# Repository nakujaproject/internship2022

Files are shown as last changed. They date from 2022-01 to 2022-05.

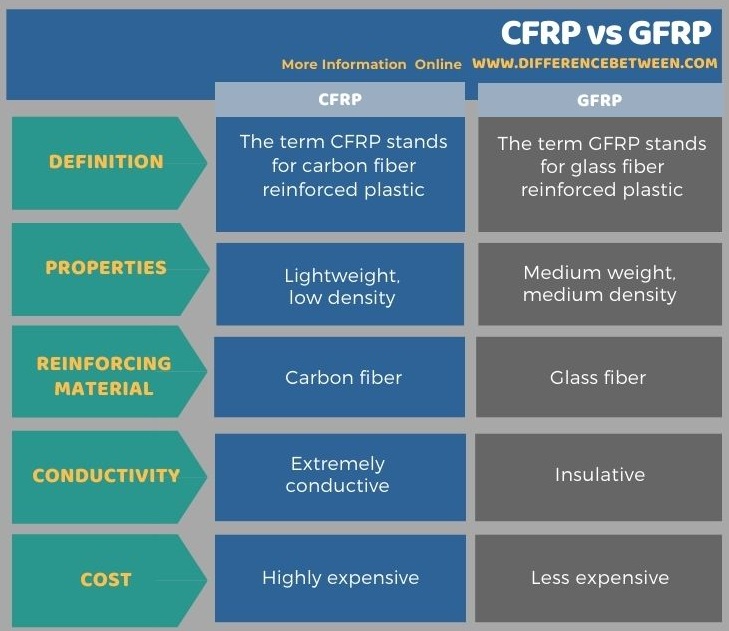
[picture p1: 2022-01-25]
Airframe/Week 1 progress/Difference-BetweenCFRP-and-GFRP-Tabular-Form.jpg

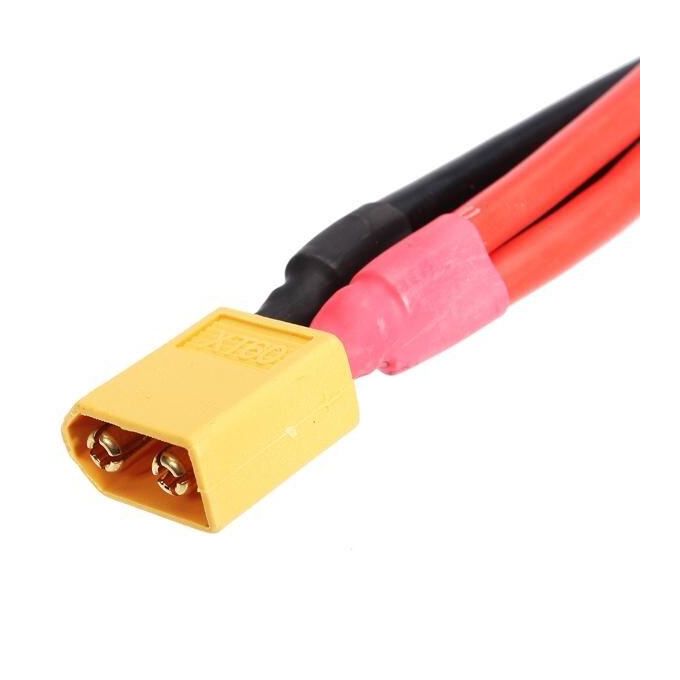
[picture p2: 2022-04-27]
avionics/AvionicsBay/xt60.jpg

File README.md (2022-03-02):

# Nakuja intern 2022

[PPT Slide](https://docs.google.com/presentation/d/1BPh0vmiUIqLUqmDDqvoZCn27pKPHvCULg1EC3PQ6zpk/edit?usp=sharing)
(https://docs.google.com/presentation/d/1BPh0vmiUIqLUqmDDqvoZCn27pKPHvCULg1EC3PQ6zpk/edit?usp=sharing)

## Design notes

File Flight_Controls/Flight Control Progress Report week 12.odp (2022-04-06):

## Internship 2022 Progress report format for Flight Control team Name: kariuki robert mukono

## Tasks completed last week

~ Preparations were made for the test flight.

~ Most of the time has been spent trying to familiarize ourselves further and further with the current code, following the directive to effectively ensure zero roll – for the sake of its modification and improvement.

## Example of code being studied

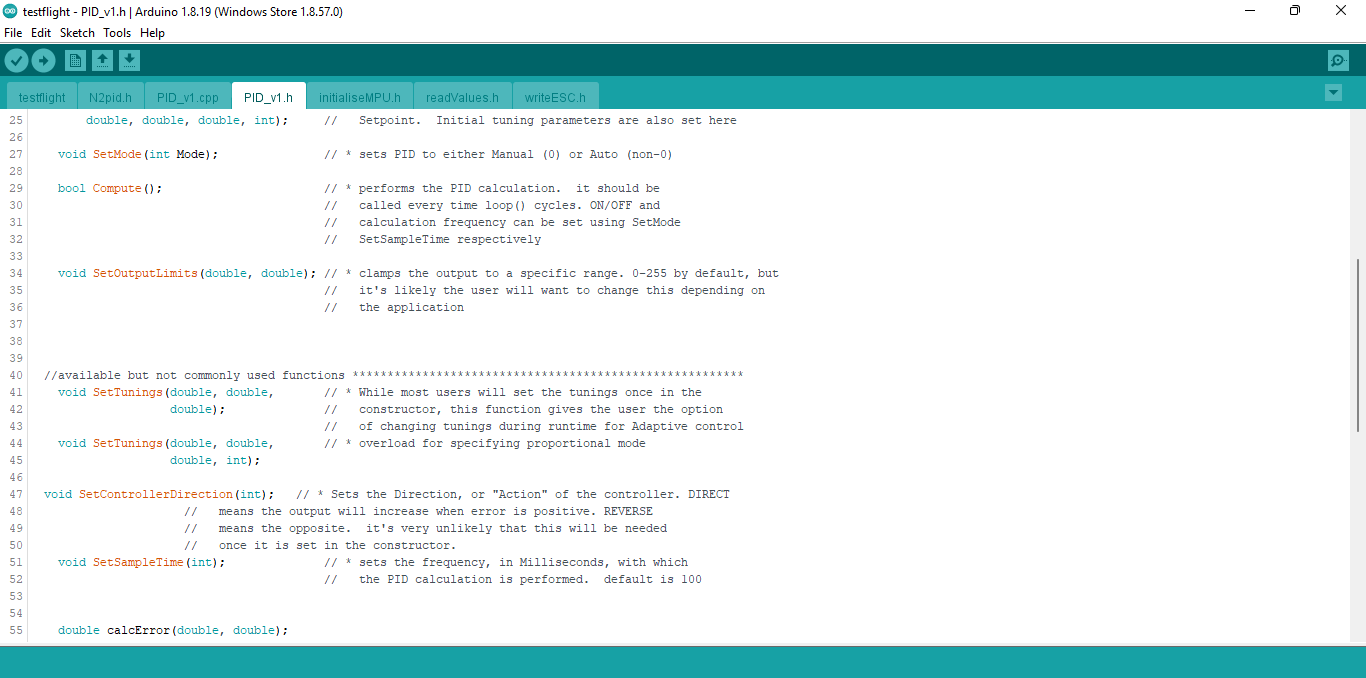
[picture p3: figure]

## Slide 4

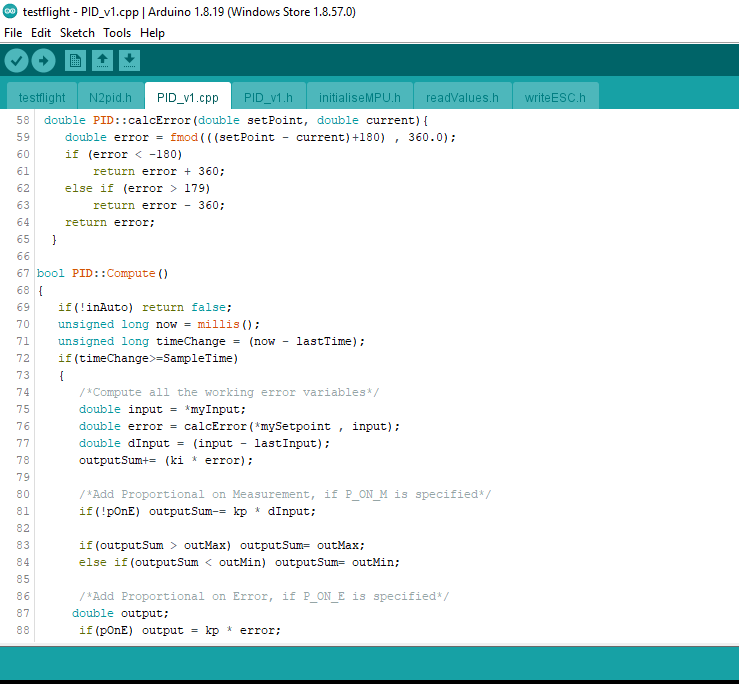
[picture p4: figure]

## Tasks in this week

~ This week we purpose to finish studying the code.

~ We also purpose to begin refining the current code.

~ We also purpose to do preliminary tests to test the effectiveness of the code.

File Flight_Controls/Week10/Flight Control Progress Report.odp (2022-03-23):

## Internship 2022 Progress report format for Flight Control team Name: kariuki robert mukono

## Tasks completed last week

- [#25] … Testing the functioning of the IR sensor

~Several tests were done at the incorporation of the IR sensor to the system, until it became functional.

~ It was noted that for proper functioning, the IR sensor must be hid from direct sunlight since it UV rays.

## [#26] … Displaying the motor speeds

~ The team strived to display the motor speed on the Arduino IDE.

~There were many challenges in the process, but finally the team was able to display the motor speed.

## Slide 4

[#27] … Motor Design

~ We designed a motor for the airframe team for the sake of simulation

## Tasks in this week

- [#25] …Further PID Tuning

~ This week we purpose to further do the PID tuning until we obtain optimum values.

~ We also purpose to incorporate RTOS into the code

~ We also purpose to do a test flight to test the effectiveness of the code.

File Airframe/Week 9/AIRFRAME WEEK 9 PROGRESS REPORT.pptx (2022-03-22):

## AIRFRAME WEEK 9 PROGRESS REPORT

BY MARK ODHIAMBO &
VIVIAN MWANGI

## GITHUB #138 NOSE CONE 3D PRINTING

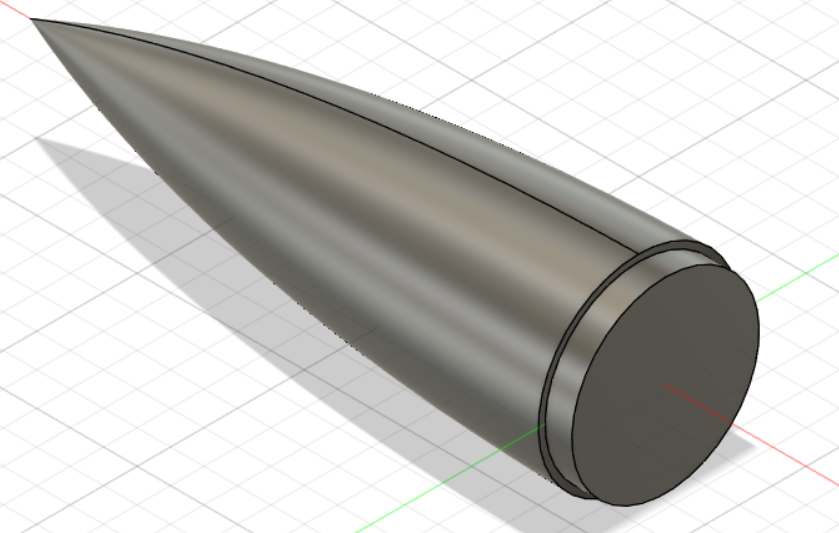
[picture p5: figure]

## GITHUB #137 RECOVERY SYSTEM

PURCHASE OF MATERIALS
WORK IN PROGRESS

## GITHUB #139 FOURTH FABRICATION.

This is the research and fabrication of the forth fabrication.
This includes the following:
- The mold cover.
- The fins.
- The accuracy.

## GITHUB ISSUE TO BE DONE.

- Github # Forth fabrication.
- Github # Ejection test

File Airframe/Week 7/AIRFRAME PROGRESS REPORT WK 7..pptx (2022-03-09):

## AIRFRAME PROGRESS REPORT WK.7 MARK ODHIAMBO AND VIVIAN MWANGI.

## GITHUB #114[UPDATED THE CAD DESIGN.]

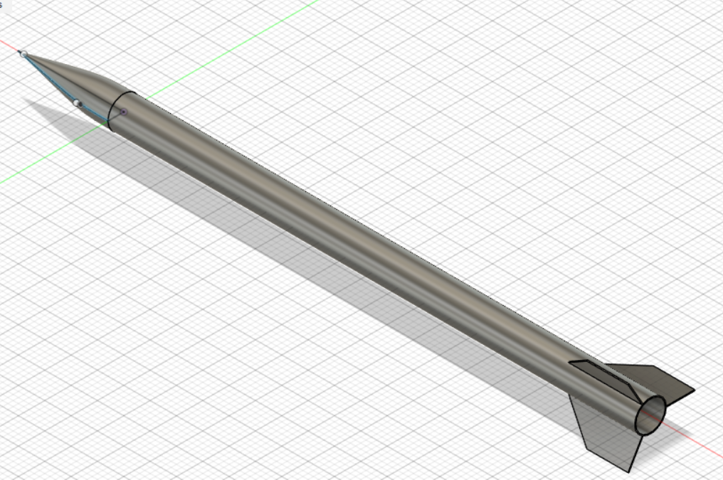
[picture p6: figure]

## GITHUB #93[CFD SIMULATION]

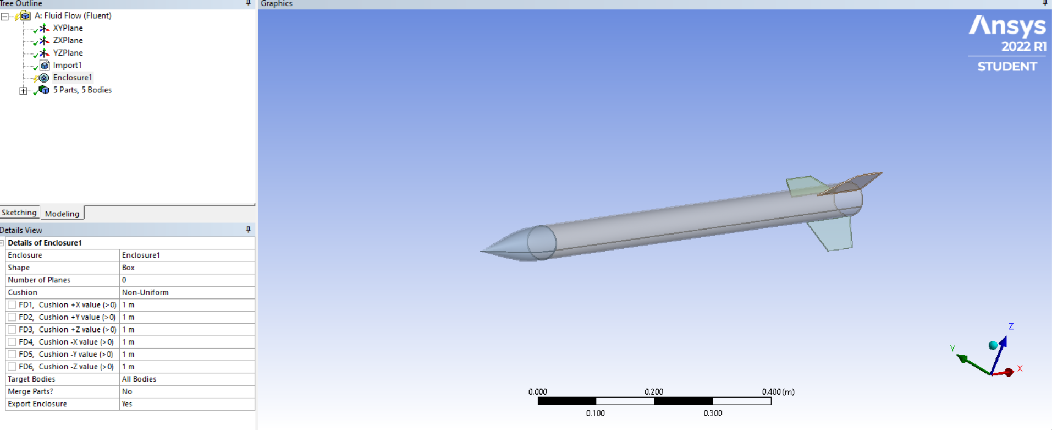
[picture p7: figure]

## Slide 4

Error in the cfd simulation.

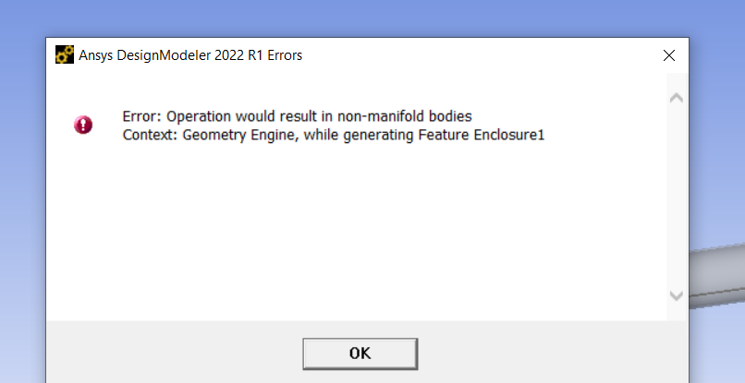
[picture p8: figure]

## GITHUB #106[THIRD FABRICATION]

The results of the third fabrication were better than that of the 2nd one the body tube had less air bubbles.
The tube should be turned to reduce thickness.

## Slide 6

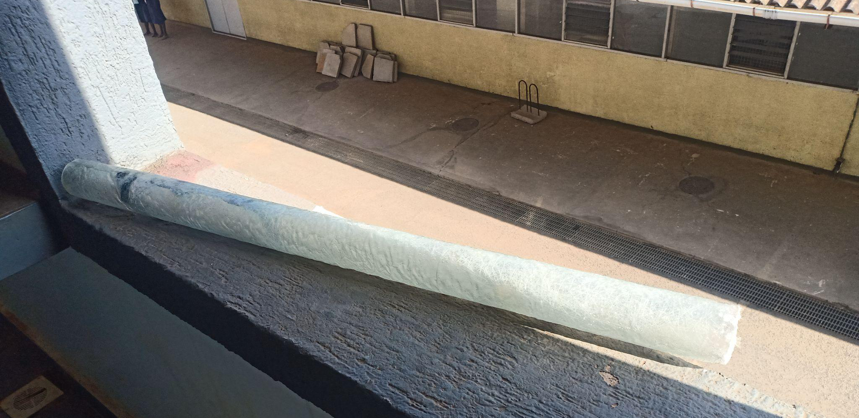
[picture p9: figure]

## TASKS TO BE DONE.

GITHUB #115 [3D PRINT NOSE CONE]
GITHUB #116 [MATERIAL ACQUISITION(RESIN)]
GITHUB #117 [POST FABRICATION OF BODY TUBE]

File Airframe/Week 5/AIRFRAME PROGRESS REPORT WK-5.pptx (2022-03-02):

## AIRFRAME PROGRESS REPORT

MARK ODHIAMBO & VIVIAN MWANGI

## [Github issue #95]Research on rocket stability tests

This is the test to be done to ensure that the rocket is stable and does not destablize during launch.
So the method found was the swing test.

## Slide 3

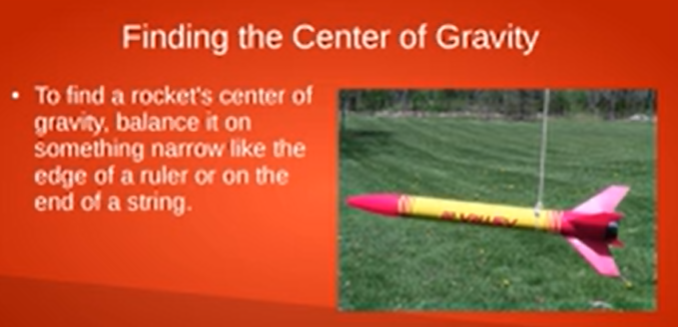
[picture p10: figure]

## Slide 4

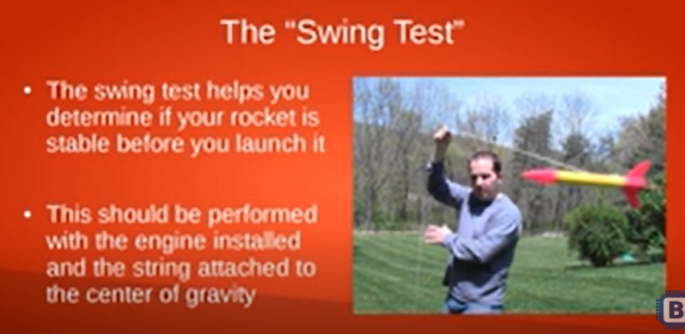
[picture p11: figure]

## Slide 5

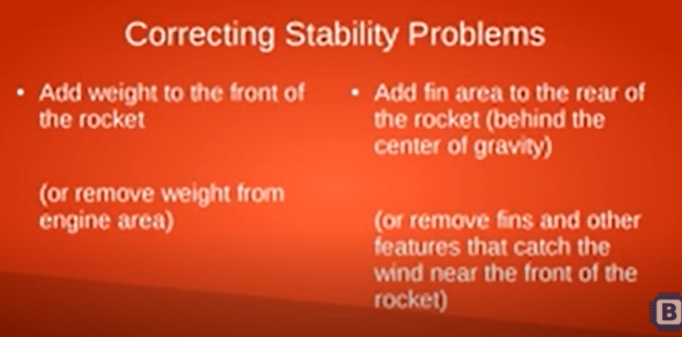
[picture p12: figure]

## [Github issue#78]Engine block design

This is the block to hold the engine in place

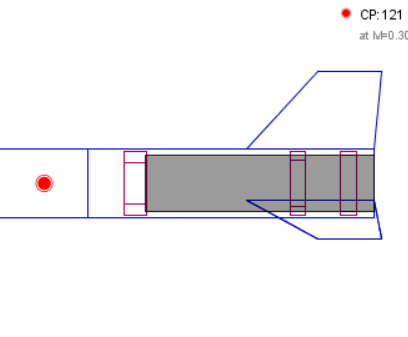
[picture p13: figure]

## CAD Design

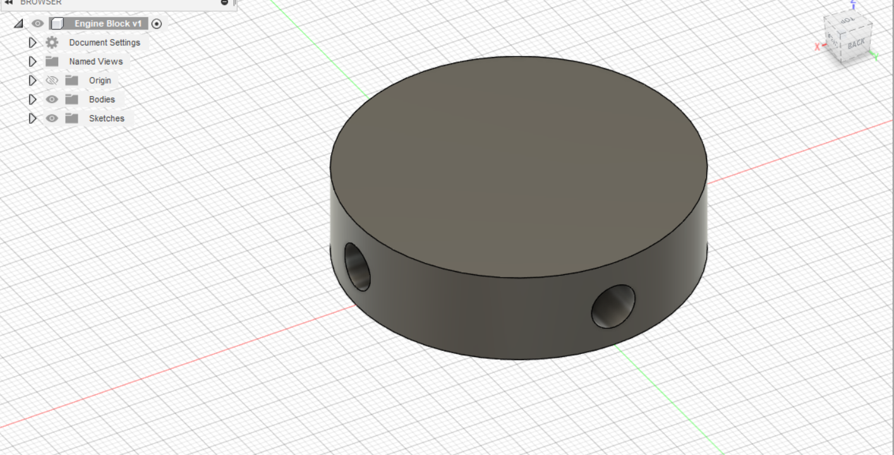
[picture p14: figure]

## [Github issue#80]Camera mount design

This is the bay which will shield host the camera of the rocket

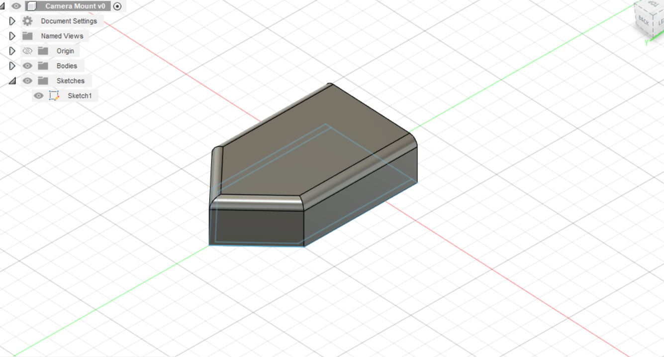
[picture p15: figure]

## [Github issue#80] Tee slot design

This is the launch rug or the component that will hold the rocket for its initial launch

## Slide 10

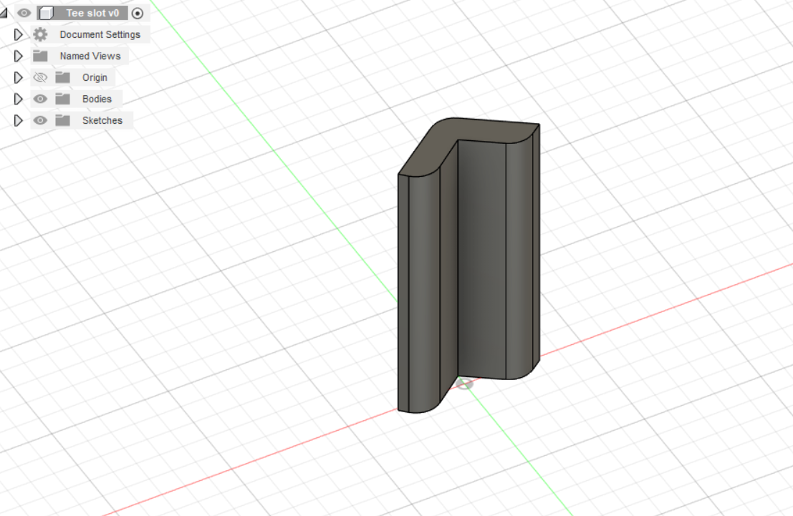
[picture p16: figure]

## Issues to be done.

- Research of fabrication of fins and nose cone[Github issue#94]
- Preparation for the third round of fabrication

## TIMELINE.

- WEEK 1-material SELECTION, ANALYSIS AND COST
- WEEK 2-DESIGN AND SIMULATION.
- WEEK 3-SIMULATION CORRECTIONS.
- WEEK 4-ASSEMBLY AND FABRICATION.
- WEEK 5-ASSEMBLY AND FABRICATION.
- WEEK 6- RECOVERY SYSTEM
- WEEK 7-FINALISATION.
- WEEK 8-TAKE OFF.
- PRONE TO CHANGE AS PER THE SITUATION.

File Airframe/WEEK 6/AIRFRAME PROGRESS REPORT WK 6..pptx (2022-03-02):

## AIRFRAME PROGRESS REPORT

Mark Odhiambo & Vivian Mwangi

## Github #104[Update of the Rocket in openRocket.]

This is the updated rocket design factoring both the design consideration of both the avionics and flight control.

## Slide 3

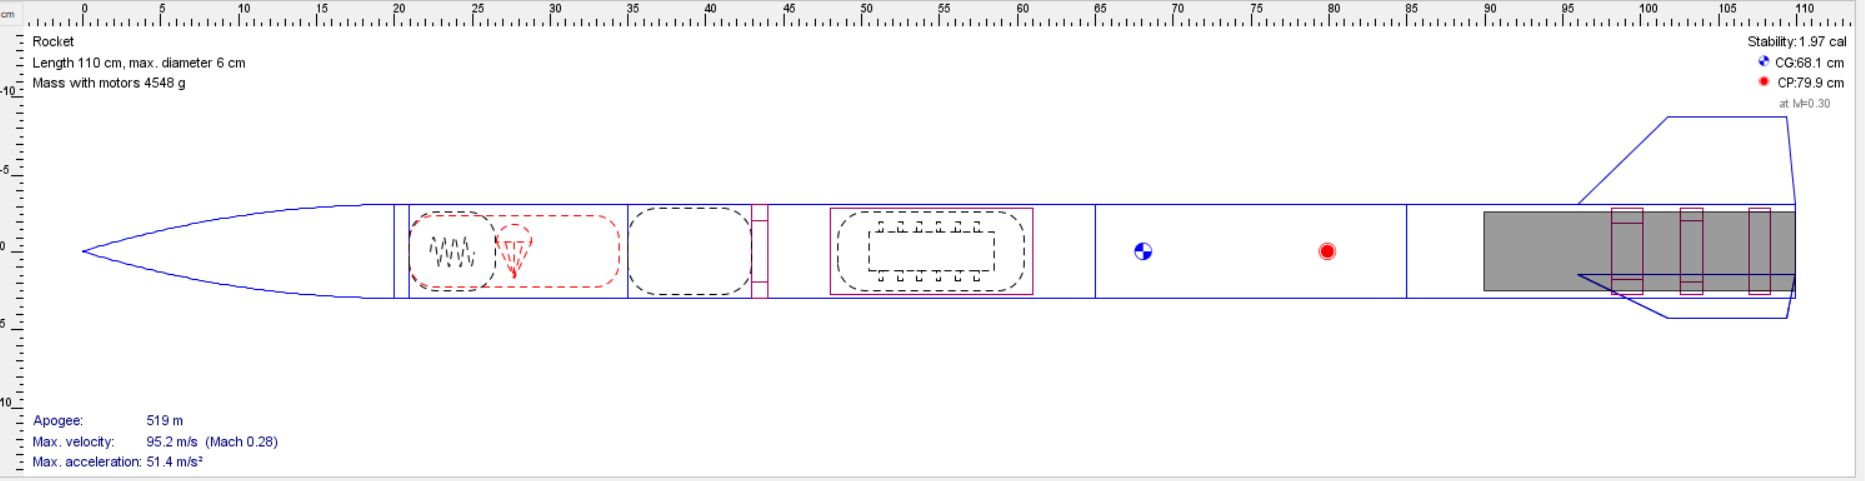
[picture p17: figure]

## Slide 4

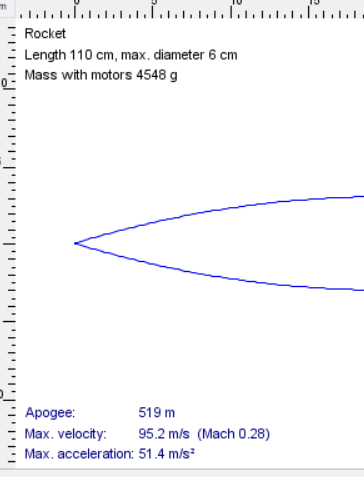
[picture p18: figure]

## Github #94 Research and fabrication of fins

It was determined that for accuracy the cones will be printed.
This was one of the factors that where considered for the rocket redesign.

## Github #105 Rocket recovery system

Different types of deployment.
- Single
- Dual

## Testing of recovery system.

Ground deployment.
After the final configuration of the rocket the final.
The rocket is tested by ground deployment. This is when the rocket is kept to the ground and ejected.

## Issues to be done

[Github #106] Third fabrication.
[Github #105] Rocket recovery system

## TIMELINE.

- WEEK 1-MATERIAL SELECTION, ANALYSIS AND COST
- WEEK 2-DESIGN AND SIMULATION.
- WEEK 3-SIMULATION CORRECTIONS.
- WEEK 4-ASSEMBLY AND FABRICATION.
- WEEK 5-ASSEMBLY AND FABRICATION.
- WEEK 6- RECOVERY SYSTEM
- WEEK 7-FABRICATION.
- WEEK 8-TAKE OFF.
- PRONE TO CHANGE AS PER THE SITUATION.

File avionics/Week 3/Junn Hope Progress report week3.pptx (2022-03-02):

## Nakuja Internship Avionics Progress Report Week 3 Junn Hope

## Tasks completed last week

- [#Issue 30] : Research on camera module
- [#Issue 51]: Inquire about GEGIS drone
- [#Issue 30] : Research on Ground Station Dashboard – In progress

## [#Issue 30] : Research on camera module

- We researched on plausible camera modules that we can use for video transmission in real time form the rocket to the ground station.
- We tested two modules:
  1. ESP32CAM
  2. FPV Drone Camera
ESP32 CAM FPV Drone camera

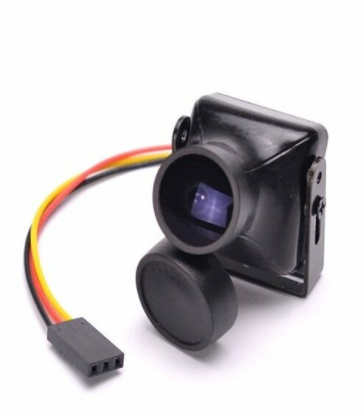
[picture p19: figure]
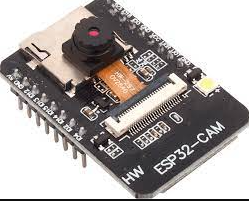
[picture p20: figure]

## ESP32 CAM

- The ESP32 cam provided clear video feed over a short range, beyond which the clarity was significantly reduced and video lag increased.
- However, these results are dependent on the Wi-Fi strength of the network to which the ESP32 is connected to.
- The results of the test carried out are as shown in the figures below:
Wi-Fi signal strength

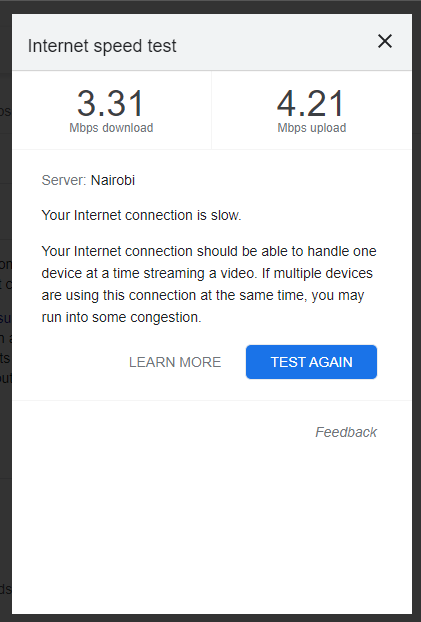
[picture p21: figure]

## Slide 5

- Clarity of ESP32 at varying distances

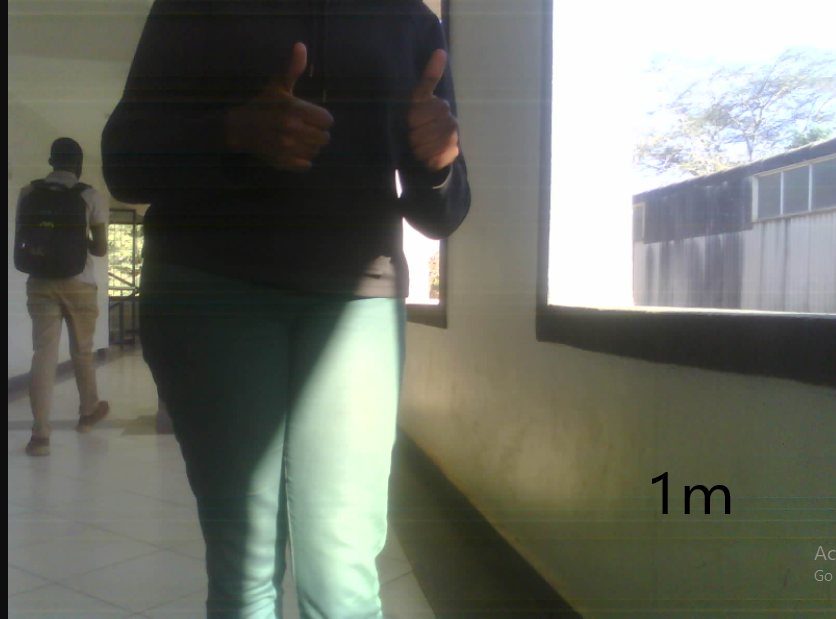
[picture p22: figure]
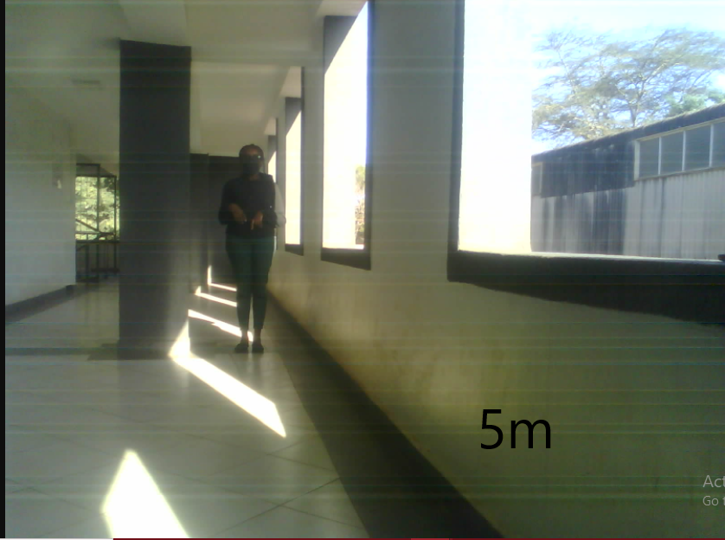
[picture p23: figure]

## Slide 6

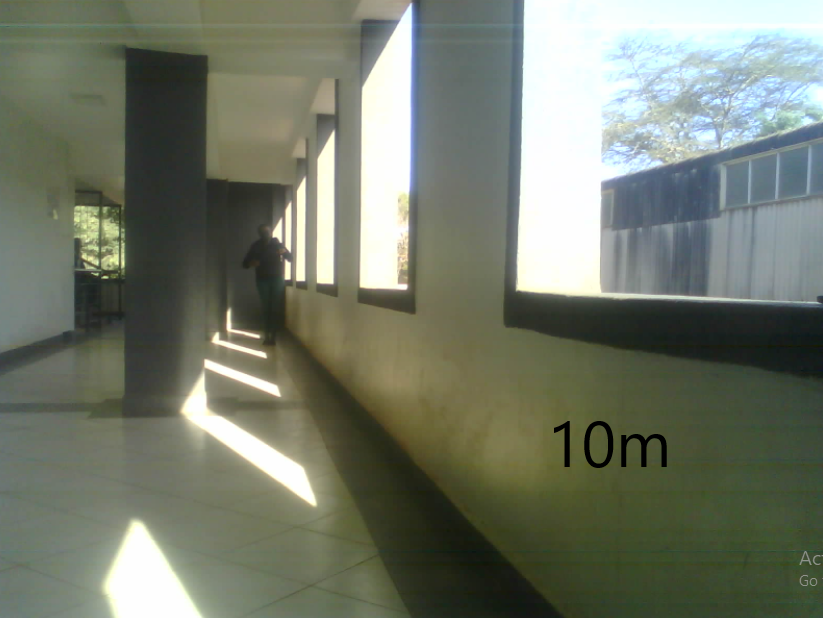
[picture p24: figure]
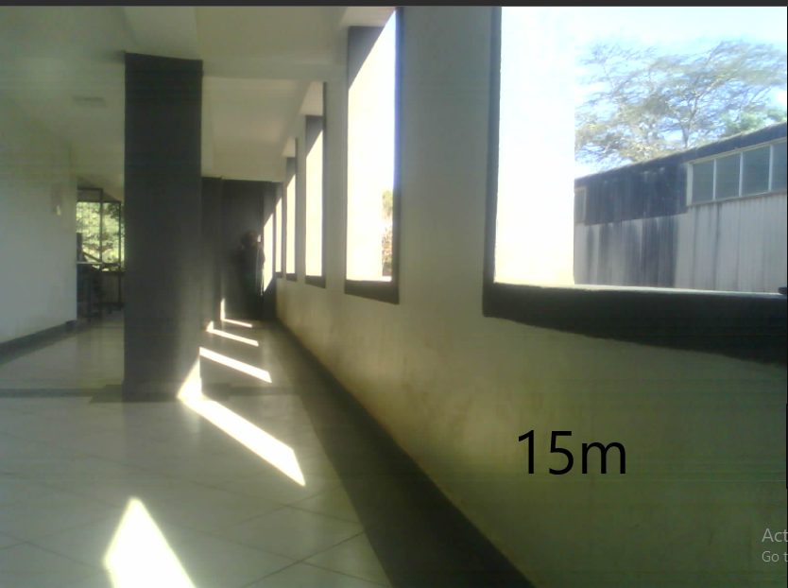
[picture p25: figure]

## FPV Drone Camera

- We tested the FPV drone camera that gave impeccable results over a greater distance of up to 1km.
- We noticed that the pointing direction of the receiving and transmitting antennas affected the clarity of the reception.
- The camera and its antennas must be connected to 12v supply, which is 4.6volts above our intended 7.4V supply.
- The test results are as shown in the figures below

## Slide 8

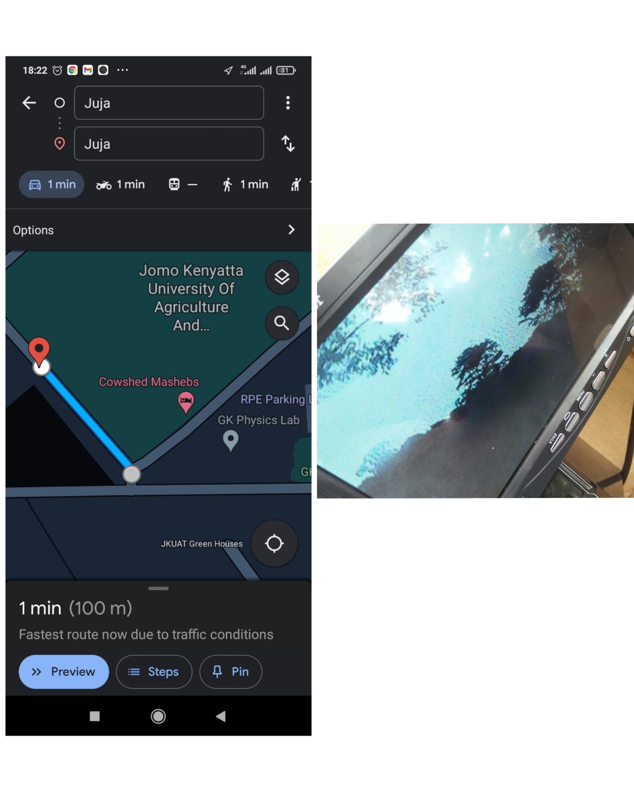
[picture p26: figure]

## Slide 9


## [#Issue 51]: Inquire about GEGIS drone

- Following week 2’s inquiry on the drone, we got the go ahead to use the drones for the tests.
- The tests are to be done on Week 5.

## Tasks in this week

- [#Issue 3]: Avionics bay design
- [#Issue 18] : Launch pad design
- [#Issue 30] : Research on Ground Station Dashboard
- [#Issue 31] : Research on apogee detection logic
- [#Issue 26] : Improve on Kalman filter performance

## Timeline

Month | Intern week | Tasks
Jan | Week 1 | Onboarding Getting acquainted with avionics and telemetry resources
| Week 2 | Research on ground station & ground station dashboard Research on camera module Research on Data transmission
| Week 3 | Avionics bay design Launch pad design
Feb | Week 4 | Research on apogee detection logic Improve Kalman filter performance
| Week 5 | Program Avionics and Telemetry boards
| Week 6 | Test the boards
| Week 7 | Testing and launch of N2

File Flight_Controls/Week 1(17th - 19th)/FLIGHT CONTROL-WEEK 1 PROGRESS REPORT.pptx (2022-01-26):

## Nakuja Internship Week 1 Progress Report

FAITH CHELANGAT
&DERRICK KIRIMI

## Tasks completed last week

- Familiarise myself with the project
- Soldering on the prototype
- Redesigning the reaction wheel

## Tasks to be completed in the following week

- Design of the N2 reaction wheel
- Logging of data onto the SD card
- Research on the mounting case and safety cage of the reaction wheel

## schematic


## Timeline

Month | Week | Tasks
January | Week1 | Familiarising with the N1/N2 project Soldering of prototype flight control PCB Research on the design of reaction wheel
| Week2 | Design of the N2 reaction wheel Logging of data onto the SD card Research on the mounting case and safety cage of the reaction wheel
| Week3
| Week4

February | Week1 | Design of the mounting case and safety cage of the reaction wheel
| Week2 | Research on Kalman Filter and ways to improve it
| Week3
| Week4

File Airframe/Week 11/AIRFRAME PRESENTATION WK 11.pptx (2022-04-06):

## Airframe weekly progress report.

MARK ODHIAMBO & VIVIAN MWANGI.

## Github #155: test flight review.

This is the review of the mistakes of the test flight.
- Recovery system.
- Fins
- Body tube

## REcovery system

Test under actual conditions
Attachment of the parachute
Release of the parachute

## fins

Orientation of the fins.
Attachment of the fins to the rocket

## Body tube

Inner body tube for component placing.
The launch rage redesign.
Extra: Painting the body tube

## Github #156: fifth fabrication.

This is the research on method for improving the fifth fabrication.
- Mold release
- Torch gun or blowdryer.

## Tasks to be done.

#156: body tube fabrication.

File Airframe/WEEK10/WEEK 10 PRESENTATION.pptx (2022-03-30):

## WEEK 10 PRESENTATION AIRFRAME

BY VIVIAN MWANGI &
MARK ODHIAMBO

## TASKS COMPLETED THIS WEEK

- RECOVERY SYSTEM FABRICATION #137
- MATERIAL ACQUISITION(RESIN) &CONSUMABLES #116
- 3D PRINT NOSE CONE #115
- FOURTH BODY TUBE FABRICATION #152

## 3D PRINT NOSE CONE #115


## RECOVERY SYSTEM FABRICATION #137

- Parachute model was tailored to the required dimensions


## FOURTH BODY TUBE FABRICATION #152

- Improvements made:
  - Less air bubbles
  - Measurements taken into account


## TASKS IN THIS WEEK

- FIN SET FABRICATION #139
- NOSE CONE FABRICATION #138
- RECOVERY SYSTEM TESTING #153
- TEST LAUNCH #111

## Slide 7

THANK YOU!


-THE END-

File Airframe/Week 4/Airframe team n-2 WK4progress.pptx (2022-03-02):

## Airframe team n-2 rocket wk4

VIVIAN MWANGI
&
MARK ODHIAMBO


## CRADLE FABRICATION

- We started on cradle fabrication.
- This included marking out of the purchased wood blocks , cutting to required shapes and then filing to obtain a fine surface finish
- We assembled the fabricated wood to a stand plate for the purpose of enhancing stability.
- See illustration on the pictorial slide

## Cad design / Pictorial for cradle


## Body-tube fabrication

- We managed to make two prototypes for the body-tube.
- Method used:
    - We set out our workstation in an open area
    - We analyzed and read the chemical safety guidelines
    - We wrapped nylon paper on our body tube mold and stuck it with tape
    - We mixed resin and catalyst in directed proportions and stirred
    - Using a brush we applied the resin to the fiberglass until we obtained desired thickness
    - We left the fiber glass body tube to dry
    - We disassembled the nylon from the body tube

## Pictorial of fabricated body-tubes


## Analysis of the fabrication process

- From our first prototype, it was discovered that several air bubbles were formed after the body-tube dried.
- It was also discovered that the thickness of the body tube was very large and it was necessary to reduce the weight
- From our second prototype, we tried to eliminate the air bubbles and at the same time reduce the thickness of the tube
- The air bubbles were observed to have reduced significantly
- The thickness of the tube was smaller than anticipated
- The nylon laid at the beginning made the interior of the tube have wrinkles

## Defects present analysis

1. Formation of air bubbles
HOW TO REDUCE:
    - MAKE THE ANGLE OF APPLICATION/SPREADER AS LOW AS POSSIBLE TO AVOID SCRAPPING OFF FRESH RESIN
    - FIRMLY DRAG THE SPREADER USING LONG AND OVERLAPPING STROKES
    - CONSIDER USING A ROLLER FOR APPLICATION INSTEAD OF BRUSH
2. Formation of wrinkles on the interior
HOW TO REDUCE:
    - MAKE SURE THERES A TIGHT FIT BETWEEN THE BODYTUBE MOLD AND THE BASE NYLON PAPER USED TO AVOID WRINKLES FORMATION

## Tasks done this week

- BODY RIG DESIGN {GitHub issue # 79}
- BODY TUBE FABRICATION {GitHub issue # 82}
- ANALYSIS OF FABRICATION {GitHub issue # 89}
- SECOND FABRICATION OF BODY TUBE {GitHub issue #90 }
- ANALYSIS OF SECOND FABRICATION OF BODY TUBE {GitHub issue #91}

## Tasks in this week

- Computational simulation of the rocket [Github issue#93]
- Tee slot design [Github issue#80]
- Engine block design[Github issue#78]
- Camera mount design[Github issue#80]

## timeline

- WEEK 1-material SELECTION, ANALYSIS AND COST
- WEEK 2-DESIGN AND SIMULATION.
- WEEK 3-SIMULATION CORRECTIONS.
- WEEK 4-ASSEMBLY AND FABRICATION.
- WEEK 5-ASSEMBLY AND FABRICATION.
- WEEK 6- RECOVERY SYSTEM
- WEEK 7-FINALISATION.
- WEEK 8-TAKE OFF.
- PRONE TO CHANGE AS PER THE SITUATION.

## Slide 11

THE END
THANK YOU!

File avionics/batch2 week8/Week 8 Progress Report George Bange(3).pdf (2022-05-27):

# Week 8 Progress Report

ENE221-0109/2017
GEORGE BANGE

# Tasks

- Issue #157 (https://github.com/nakujaproject/internship2022/issues/157) : RTOS optimization
- Issue #158 (https://github.com/nakujaproject/internship2022/issues/158) : Ground Station Parachute Manual override
- Issue #159 (https://github.com/nakujaproject/internship2022/issues/159) : Write telemetry data to flash memory during flight

# RTOS optimization

2 queues instead of 1

Reduced number of data points being sent over LoRa

LoRa - we are sending timestamp,altitude and state

SD card/SPI flash memory - timestamp, altitude, raw and filtered gyro and acceleration values, state, gps latitude and longitude

# RTOS Queues


# Ground station Manual Override

Rocket watches out for data packets from ground station

Update state to deploy parachute if it fails

Update ground state to start sending gps data

# Write Data to SPI flash memory

ESP32 has 4MB non-volatile flash memory

Write to flash memory incase SD card fails like in test flight

# Tasks Next week

- Issue #160 (https://github.com/nakujaproject/internship2022/issues/160) : Test GPS inside fibre glass body tube
- Test software on breadboard

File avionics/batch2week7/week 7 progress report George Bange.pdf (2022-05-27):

# Week 7 Progress Report

George Bange
ENE221-0109/2017

# Tasks

- Measure Time taken to execute different tasks
- Implement Real Time OS
- Manual override for parachute ejection
- Launch Test

# Measuring Time per Task

We timed the tasks and noticed that GPS takes the most amount of time (2 s) hence

To leverage the dual-core nature of ESP32-S, we decided to divide the tasks between the cores using FreeRTOS library in ESP-IDF

Core 0: Fetch Telemetry Data and Write to SD Card

Core 1: Transmit data using LoRa

TASK | Frequency (Hz) | Time (ms)
BMP and MPU | 13.88 | 72
Kalman Filter | 53070 | 0.018
Check state | 445570 | 0.00122
Format Data | 550790 | 0.00118
LoRa | 4 | 250
GPS | 0.5 | 2000
SD Card | 31.8 | 31

# ESP-IDF FreeRTOS Queue implementation


# Manual Override for Parachute ejection

We implemented manual override for parachute ejection from ground station

A command is sent over LoRa from ground station to the rocket to deploy the parachute

Other commands also exist to change states from ground station

# Test Launch

We carried out the first N2 test launch on 22nd April at the Rugby field

LoRa Transmit task worked but the connection was lost at some point. This was probably due to damage of flight computer

The highest recorded altitude was 1870m.


Rocket at take-off

# Challenges and Lessons

- FreeRTOS: Corruption of heap, ESP kept resetting
- Manual override failed
- Parachute ejection code failed
- Damage of payload
- Queue kept filling up causing some readings to be dropped
- Some packets were corrupted

# Photos of Recovered Rocket


# Photos of Recovered Rocket


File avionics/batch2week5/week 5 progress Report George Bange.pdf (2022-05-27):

# Week 5 Progress Report

### George Bange ENE221-0109/2017

# Tasks Completed

- Issue #140 (https://github.com/nakujaproject/internship2022/issues/140) : Review LoRa Module connections

### - SD card module connection - Fabrication of new PCB - Visited PAUSTI

# ESP32 pinout

Studied the ESP32-S GPIOs and their common applications

Some pins can’t be used as digital output pins, these pins are 6,7,8,9,10,11,34,35,36 and 39

All GPIOs can be used as hardware interrupt pins

ESP32-S has:

i. 18 ADC interfaces
ii. | 4 SPI interfaces
iii. | 3 UART interfaces (only UART 0 and UART 1 are available for use)
iv. | 2 I2C interfaces
v. 2 DAC interfaces
vi. | 16 PMW interfaces
vii. | 2 I2S interfaces
viii. | 10 capacitive sensing GPIOs

# LoRa module connection

### HSPI (SPI2) configuration used


### MOSI -> 13, MISO -> 12, CLK -> 14, CS ->15

NODE MCU

# SD card module connection


VSPI (SP12) configuration used

MOSI -> 23, MISO -> 19, CLK -> 18, CS -> 5

# Fabrication of new PCB

We fabricated a double-sided PCB at Gear Box.

The PCB had a lot of continuity issues. Some are yet to be resolved


# Visited PAUSTI

### We visited PAUSTI to find out what antenna testing equipment they have

### The Electronics Lab has 2 VNAs and a Spectral analyzer which we will use to fabricate our antenna

### They also have PCB fabrication equipment of upto 8 layers

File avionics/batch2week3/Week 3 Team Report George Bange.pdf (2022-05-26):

# Week 3 Team Report

Presented by George Bange

# Completed Tasks

[#Issue 142]: Reverse protection circuit on PDB

[#Issue 132]: Impedance matching circuit on LoRa module

[#Issue 129]: Impedance matching circuit on ESP

[#Issue 130]: Review of RF power amplifier

[#Issue 34]: Finding a cheaper and reliable pressure sensor

[#Issue 143]: Test-Flight PCB

[#Issue 144]: Power Budget

[#Issue 3]: Research on ground station dashboard

[#Issue 50]: Design architecture for ground station

# Completed Tasks

[#Issue 2]: Research on ground station

[#Issue 31]: Research on apogee detection logic

[#Issue 40]: Test 2 reads over i2c

[#Issue 42]: Test speed and bandwidth of i2c and SPI

[#Issue 41]: Test 2 writes over SPI

[#Issue 131]: Review SD card circuit

[#Issue 144]: Power budget

[#Issue 118]: Design architecture for ground station and test stand

[#Issue 1]: Research on data transmission

# REVISION OF PDB


PDB supplies telemetry, avionics and flight control

Goal was to achieve 4A total supply current

Introduced new ICs (XP3182) with promise current 2A each

Previous IC gave current barely 1A

## PREPARATION OF TEST-FLIGHT BOARDS


Drilling will happen today

# Improvement of Yaggi-Udda Array


Introduction of a boom yielded better simulation results

# Matching Circuit for ESP chips

A matched circuit to improve RF performance. Input impedance (35 + j10 Ohms) matched to 50 Ohms


# Ground Station Flow Diagram


# Ground Station Frontend


Graphs for sensor output data (MPU and BMP ) to be put on base station website

# Routing of Telemetry PCB


Updates made to PCB and re-routing was done

# Review of BMP sensor

A new BMP(DPS310) was picked

It is cheaper than the old one with relatively good features

Most bmp were out of stock

Next task is to review the MPU sensor

Flight Control and avionics to share BMP and MPU sensors

# TODO Tasks

- [#Issue 145]: Order Telemetry Boards
- [#Issue 146]: Write Test Flight Code
- [#Issue 147]: Finish on Test stand backend services
- [#Issue 148]: Print Yaggi Udda Frame
- [#Issue 149]: Test avionics Systems on Test Flight
- [#Issue 150]: Test Flight

# Tasks This Week

1. Building, testing and tuning antennas at Pausti
2. Putting together test-flight board
3. Testing of PDB to verify currents
4. Capturing ESP32 camera video and storing on SD card
5. Integration of standalone fpv camera with ESP
6. Altitude and displacement graphs to be included in frontend

# Challenges Faced

- Where to obtain RF power splitter/combiner
- Missing components - HDMI, HDMI to mini HDMI and capture card. To be ordered

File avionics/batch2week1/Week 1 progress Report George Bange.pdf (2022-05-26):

# WEEK 1 PROGRESS REPORT

GEORGE BANGE
ENE221-0109/2017

# Getting Familiar with avionics system

The avionics system consists of:

- ESP32-S MCU
- BMP sensor
- MPU sensor

Telemetry involves recording and sending the sensor readings to the ground station

The groundstation is a second ESP32-S MCU

# Telemetry

Telemetry data is sent from rocket to ground station over WiFi

ESP 32 has inbuilt WiFi capability IEEE 802 b/g/n operating at 2.4 GHz

An onboard SD card module to telemetry data during flight as redundancy

# ESP 32 WiFi (from datasheet)


# Challenges

Some concepts were totally new to me, but am slowly getting the hang of it

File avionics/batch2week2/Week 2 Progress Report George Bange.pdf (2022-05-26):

# Week 2 Progress Report

### George Bange ENE221-0109/2017

# Tasks

- | Issue #140 (https://github.com/nakujaproject/internship2022/issues/140) | Review LoRa matching circuit

### - Testing ESP32-LR mode

# LoRa module Matching circuit

### No matching is required since the antenna is already matched at 50 ohms


# Testing LoRa LR mode

ESP32 LR(Low Rate hence Long Range) protocol promises 1km point-to-point range even without external antennas. This low data rate is 10X greater than LoRa data rates.

The best RSSI values at 70m (-64dBm). Beyond 70m the RSSI values worsened (-90 dBm)
From theory, performance below -70dBm is classified as poor

Since the ESP32 PCB antenna has only 2dBi gain, we will require an external antenna of 24dBi at the ground station to receive telemetry data reliably.

We will be re-using the ESP modules with hand-mounted ipex connectors. However, industry-calibrated ESP modules that come with already matched external connectors (ESP32 Wroom 32UE) are known to yield better results.


# ESP LR Mode

# Best RSSI


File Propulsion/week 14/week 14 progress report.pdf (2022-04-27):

NAKUJA INTERNSHIP

## WEEK 14 PROGRESS REPORT


● [#108] Remote Ignition
● [#36] Snap Ring Purchase
● [#56] Fuel Casting for Test Flight
● [#150] Test Flight

Attained Apogee = 280 m


## Bulk

## -head side Nozzle side

## The engine

## block remained intact, both sides of the

## engine where

## bolted to the

airframe.

## Using ESP32 NODE-MCU module


Libraries utilized
• Async TCP Library for ESP32
• ESPAsyncWebServer

TASKS THIS WEEK

## - [#71] Casing Fabrication - [#] Purchase of Sorbitol

Month; Intern week; Tasks; Jan; Feb; Week 4; Fabrication of items & Fuel casting

Week 1 | Designs [Fuel, Casing, Nozzle, Bulkhead, Casting tools, Teststand]

Week 2 | Fabrication of items

Week 3 | Fuel Fabrication and test stand revamp

Week 5 | Iterative Fuel tests

Week 6 | Launch Pad design and iterative fuel tests

Week 7 | Iterative fuel testing and improvement

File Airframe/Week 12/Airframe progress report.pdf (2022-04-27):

# Introduction of internship

## April 2022

## Tasks done

- Test launch report (https://nakujaproject.blogspot.com/2022/04/avionics-report-as-we-are-brains-of.html)
- Fins assembly
- Test skeleton assembly

## Tasks to be done

### - Nose cone adjustments and printing - Body tube and Fins fabrication - Item purchase - Print launch lug

## Timeplan

April 18th - 23rd | - Test launch
| - Fabricate duplicate body tubes
April 25th - 30th | Fabricate new body tube
May 2nd - 7th | Test flight

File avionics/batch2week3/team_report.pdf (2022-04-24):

# Week 3 Team Report

Presented by George Bange

# Completed Tasks

[#Issue 142]: Reverse protection circuit on PDB

[#Issue 132]: Impedance matching circuit on LoRa module

[#Issue 129]: Impedance matching circuit on ESP

[#Issue 130]: Review of RF power amplifier

[#Issue 34]: Finding a cheaper and reliable pressure sensor

[#Issue 143]: Test-Flight PCB

[#Issue 144]: Power Budget

[#Issue 3]: Research on ground station dashboard

[#Issue 50]: Design architecture for ground station

# Completed Tasks

[#Issue 2]: Research on ground station

[#Issue 31]: Research on apogee detection logic

[#Issue 40]: Test 2 reads over i2c

[#Issue 42]: Test speed and bandwidth of i2c and SPI

[#Issue 41]: Test 2 writes over SPI

[#Issue 131]: Review SD card circuit

[#Issue 144]: Power budget

[#Issue 118]: Design architecture for ground station and test stand

[#Issue 1]: Research on data transmission

# REVISION OF PDB


PDB supplies telemetry, avionics and flight control

Goal was to achieve 4A total supply current

Introduced new ICs (XP3182) with promise current 2A each

Previous IC gave current barely 1A

## PREPARATION OF TEST-FLIGHT BOARDS


Drilling will happen today

# Improvement of Yaggi-Udda Array


Introduction of a boom yielded better simulation results

# Matching Circuit for ESP chips

A matched circuit to improve RF performance. Input impedance (35 + j10 Ohms) matched to 50 Ohms


# Ground Station Flow Diagram


# Ground Station Frontend


Graphs for sensor output data (MPU and BMP ) to be put on base station website

# Routing of Telemetry PCB


Updates made to PCB and re-routing was done

# Review of BMP sensor

A new BMP(DPS310) was picked

It is cheaper than the old one with relatively good features

Most bmp were out of stock

Next task is to review the MPU sensor

Flight Control and avionics to share BMP and MPU sensors

# TODO Tasks

- [#Issue 145]: Order Telemetry Boards
- [#Issue 146]: Write Test Flight Code
- [#Issue 147]: Finish on Test stand backend services
- [#Issue 148]: Print Yaggi Udda Frame
- [#Issue 149]: Test avionics Systems on Test Flight
- [#Issue 150]: Test Flight

# Tasks This Week

1. Building, testing and tuning antennas at Pausti
2. Putting together test-flight board
3. Testing of PDB to verify currents
4. Capturing ESP32 camera video and storing on SD card
5. Integration of standalone fpv camera with ESP
6. Altitude and displacement graphs to be included in frontend

# Challenges Faced

- Where to obtain RF power splitter/combiner
- Missing components - HDMI, HDMI to mini HDMI and capture card. To be ordered

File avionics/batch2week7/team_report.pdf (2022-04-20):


# AVIONICS WEEK 8 PROGRESS REPORT

# Presented by James Macharia

# Tasks Completed last week


- Due to the trip to Malindi Space Centre not much was done during the week though some tasks were done while others are still in progress
- The new PCB was soldered and tests for continuity were conducted
- A new flight software has been worked on
- We established that the FPV camera Tx is beyond salvage

Soldering of the new PCB

# Configuration of a new RTOS

- A new Real Time Operating System was configured
- First core- Fetching Telemetry data and writing to SD card#
- Second core-Transmitting the data using Lora

RTOS Guide

# Challenges Faced


- The software does not run on the PCB and we are yet to establish the problem
- LoRa datastream is generally slow hence the team will be migrating to Wifi after the testflight

# FPV CAMERA


- It was established that the FPV camera transmitter was beyond salvage
- However the receiver is perfectly fine and functional
- We will be requesting another transmitter from Pixel Electronics in the course of the day
- The camera setup might be ready on time for the test flight if the transmitter is delivered on time


# Tasks This Week

- Fabricate New PCB
- Integration of Flight Control

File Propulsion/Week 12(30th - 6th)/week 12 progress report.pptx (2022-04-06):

## Nakuja internship

WEEK 12 PROGRESS REPORT

## TASKS COMPLETED THIS WEEK

- [#71] Casing Fabrication
- [#56] Fuel Casting
- [#68] Remote Ignition Testing

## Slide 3

#71 Casing fabrication


We fabricated a smaller casing to be used for the test launch scheduled for a later date

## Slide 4

#56 Fuel Casting


We prepared two grains of fuel. The mixing ratio was 67:33 potassium nitrate to sorbitol, 4g of iron oxide. The grains will be used in a static test to be conducted today.

## Tasks this week

- [#150] Test Flight
- [#] Snap Ring Purchase

## timeline

Month | Intern week | Tasks
Jan
| Week 1 | Designs [Fuel, Casing, Nozzle, Bulkhead, Casting tools, Test stand]
| Week 2 | Fabrication of items
| Week 3 | Fuel Fabrication and test stand revamp
Feb | Week 4 | Fabrication of items & Fuel casting
| Week 5 | Iterative Fuel tests
| Week 6 | Launch Pad design and iterative fuel tests
| Week 7 | Iterative fuel testing and improvement

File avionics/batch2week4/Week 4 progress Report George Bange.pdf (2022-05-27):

# Week 4 Progress Report

George Bange
ENE221-0109/2017

# Tasks

- Testing LoRa Receiver
- Testing ESP 32 WiFi

# LoRa receiver


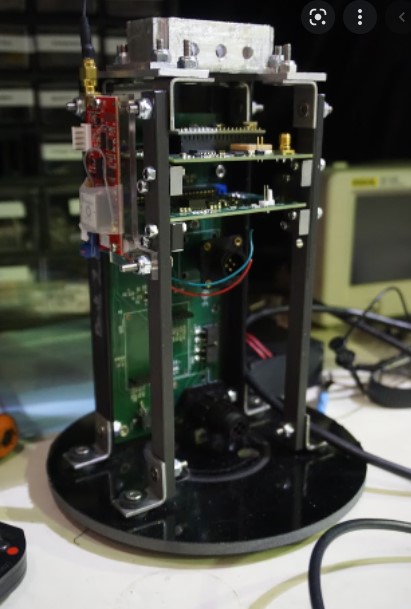
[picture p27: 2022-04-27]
avionics/AvionicsBay/trbay.jpg

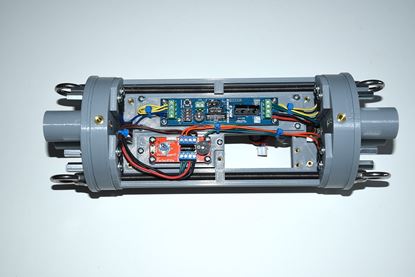
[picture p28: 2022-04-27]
avionics/AvionicsBay/abay-2.jpeg

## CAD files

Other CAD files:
Airframe/CAD/N-2 rocket assembly1.iam
Airframe/CAD/N-2 rocket assembly2.iam
Airframe/CAD/body tube n-2.ipt
Airframe/CAD/extratube1.ipt
Airframe/CAD/extratube2.ipt
Airframe/CAD/fin set.ipt
Airframe/CAD/nose cone n2.ipt

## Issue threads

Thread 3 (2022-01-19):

Research on the ground station dashboard

0x6f736f646f, 2022-01-19:
# Research on the ground station dashboard

## Requirements

It should be able:
- Observability will allow you to ask questions about your system in real-time
- Relay video capture
- Monitor system logs from flight computers
- Monitor data, altitude, velocity etc from the onboard telemetry computer
- Should be able to run in a raspberry pi preferably in a docker container
- Should be easy to use

## Deliverables

One solution that you are comfortable with and we can work on it

## References

- Checkout [grafana](https://grafana.com/)
- Checkout [prometheus](https://prometheus.io/)
- Checkout [Javascript web frameworks](https://hackr.io/blog/best-javascript-frameworks)
- Checkout [Nasa Telemetry dashboard](https://github.com/nasa/openmct-tutorial)
- https://github.com/psas/launch-tower-comm
- https://www.youtube.com/watch?v=fYsA3T8rlhg
- https://github.com/psas/telemetry

Closed 2022-03-23.

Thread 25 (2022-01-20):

Test reaction wheel on test bench with current software

SammyOina, 2022-01-20:
- [ ] Run test
 - [ ] record results

SammyOina, 2022-01-20:
Tests should be iterative and resulting data shared in google drive

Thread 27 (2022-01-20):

Design Safety Cage for reaction wheel

SammyOina, 2022-01-20:
The case should hold the reaction wheel in case it comes loose
- [x] Drawing

Kinder2001, 2022-03-01:
[https://a360.co/3K8VXf4](url)

Kinder2001, 2022-03-01:
The safety cage will consist of the top case held on to the mounting case by screws of about 60mm

Closed 2022-03-01.

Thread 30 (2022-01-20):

Research on camera.

Mike-Kimani, 2022-01-20:
Find the most suitable on rocket camera to record a video of the flight.

bytecod3, 2022-02-08:
An RF FPV camera with a TFT-LCD monitor gave good results during testing. It can be attached to the body of the rocket during flight to record and transmit flight video. The camera was able to transmit good stream up to distances of 1.1 km.
Images of the test can be seen here - https://github.com/nakujaproject/N2Avionics-playground/commit/befeffd551427fd049c06108e2e3de7c9344d042

We noticed signal quality is great when antennas are upright than when they are pointed at each other

junn-hope, 2022-02-09:
The ESP32 CAM proved to have good resolution over a very short distance of up to 5m, however, this result is tied to the strength of the Wi-Fi to which it is connected to.

Beyond 15m, the camera lost its clarity. Abstracting from this results, I would not recommend it for use for N2- 500m apogee goal.

0x6f736f646f, 2022-03-29:
Done

Closed 2022-03-29.

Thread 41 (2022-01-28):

Test two writes over SPI

0x6f736f646f, 2022-01-28:
# Test two writes over SPI

## Requirements
Write different data to different slave devices, i.e arduinos or esp

## Deliverables
Can it work and how does it work

## References
1. http://www.learningaboutelectronics.com/Articles/Multiple-SPI-devices-to-an-arduino-microcontroller.php
2. https://www.microchip.com/forums/m778906.aspx
3. https://www.skyworksinc.com/-/media/Skyworks/SL/documents/public/application-notes/an926-reading-writing-registers-spi-i2c.pdf

Closed 2022-03-23.

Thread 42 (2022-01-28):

Test speed and bandwith of i2c and SPI

0x6f736f646f, 2022-01-28:
# Test speed and bandwith of i2c and SPI

## Requirements
- test if spi reaches 60 Mbps
- test if i2c reaches up to 400 kbit/s in the Fast-mode, up to 1 Mbit/s in Fast-mode Plus, or up to 3.4 Mbit/s in the High-speed mode

## Deliverables
Max speed and bandwidth

## References
1. https://www.nxp.com/docs/en/user-guide/UM10204.pdf
2. https://www.i2c-bus.org/speed/
3. https://www.analog.com/media/en/technical-documentation/product-selector-card/i2Cb.pdf

0x6f736f646f, 2022-03-23:
We will go with theoretical

Closed 2022-03-23.

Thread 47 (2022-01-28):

Test speed and bandwidth of gsm module

0x6f736f646f, 2022-01-28:
# Research on data transmission

## Requirements
Test max speed over 2G and 3G

## Deliverables
Arduino code

## References
1. https://www.circuitstoday.com/interface-gsm-module-with-arduino
2. https://lastminuteengineers.com/sim800l-gsm-module-arduino-tutorial/
3. https://how2electronics.com/send-gsm-sim800-900-gprs-data-thingspeak-arduino/

0x6f736f646f, 2022-03-29:
We will use theoretical

Closed 2022-03-29.

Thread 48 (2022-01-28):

Test max distance of lora

0x6f736f646f, 2022-01-28:

0x6f736f646f, 2022-01-29:
@Mike-Kimani provide the specs for this

bytecod3, 2022-02-07:
Done by this https://github.com/nakujaproject/N2Avionics-playground/commit/1af6415088bc62bf34250a2641d6748b4dcc1741
Using two generic antennas with a signal strength of  2.0dBi and RSSI value of +- 4dB, reception of data packets was very poor  within 500m range

0x6f736f646f, 2022-02-09:
What about increasing the power?

0x6f736f646f, 2022-03-29:
We will use theoretical

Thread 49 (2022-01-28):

Inquire about JKUAT satellite

0x6f736f646f, 2022-01-28:
# Inquire about JKUAT satellite

## Requirements

## Deliverables

## References

0x6f736f646f, 2022-01-29:
@junn-hope  provide the specs for this

junn-hope, 2022-02-01:
@0x6f736f646f  We met the person in charge of this satellite on Monday,31st January. He confirmed that our idea of routing our traffic through this satellite can be done by creating a Wi-Fi network around our test area delivered by antennas set up point to point from transmitting antennas at Tech House. The Wi-Fi shall set up by a router connected to the receiver antenna. We can then configure our ESP32s, RaspberryPi and PCs to the same network.

A setup cost of approximately Ksh 30,000 was identified to coater for the cost of setup and for bandwidth.

0x6f736f646f, 2022-03-29:
Will not be implemented

Closed 2022-03-29.

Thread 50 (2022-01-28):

Design architecture for ground station

0x6f736f646f, 2022-01-28:
# Design architecture for ground station

## Requirements
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

@junn-hope upload the requirements for this issue

## Deliverables

- [ ] System architecture
- [ ] Sample demo

## References
1. http://mgsn.sourceforge.net/docs/arch1.1.php
2. http://openaccess.uoc.edu/webapps/o2/bitstream/10609/34981/7/jramosperezPFC0614memoria.pdf

junn-hope, 2022-02-01:
@0x6f736f646f , @Mike-Kimani
Open for review, this was our idea on how the architecture shall look like.

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

0x6f736f646f, 2022-02-01:
It is not yet done until approval

0x6f736f646f, 2022-02-01:
Can you outline the steps in each process e.g

In Manager
- Receive data from esp32 receiver
- Decode the data
- Store the data
- Display the data

0x6f736f646f, 2022-02-01:
> @0x6f736f646f , @Mike-Kimani Open for review, this was our idea on how the architecture shall look like.
>
> 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

Good job @junn-hope and @bytecod3

Closed 2022-03-23.

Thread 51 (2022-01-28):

Inquire about Gegis drones

0x6f736f646f, 2022-01-28:
# Inquire about Gegis drones

## Requirements

## Deliverables

## References

0x6f736f646f, 2022-01-29:
@junn-hope  provide the specs for this

junn-hope, 2022-02-01:
@0x6f736f646f
I have spoken to the person in charge of the GEGIS drones, Mr Lazarus, he says the drones are available for  use. However, we have to request for them from the GEGIS department chair through our supervisor-Dr Aoki. I shall table this during tomorrow's meeting

An issue over KCAA regulation for our intended flying height was raised; as JKUAT is currently licensed to fly below 117m. I would suggest for test purposes, we keep within the regulated height.

shohei, 2022-02-01:
@junn-hope Thank you for the update. Can you draft the letter to request the drone use of GEGIS department?
For the KCAA regulation, I'm still in touch with the KSA for how we proceed with the flight waiver. We'll comply with the 400 feet regulation until we get the clearance from the authority.

junn-hope, 2022-02-01:
@shohei  Yes sir I shall draft the letter and deliver by close of business.

Closed 2022-03-29.

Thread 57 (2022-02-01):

Research on the use of snap rings

WashingtonKK, 2022-02-01:
Snap rings could be used as an alternative to bolts for securing the bulkhead and nozzle in place.
They are fitted into internally machined grooves that are easier to align and fit.

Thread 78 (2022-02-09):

Engine Block

MarkOdhiambo, 2022-02-09:
This is the design of the block that will prevent the engine from going forward in the body tube.

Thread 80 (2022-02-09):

Tee slot design

MarkOdhiambo, 2022-02-09:
The design of the tea slot for the launch pad for stability during the launch of the rocket

Closed 2022-05-04.

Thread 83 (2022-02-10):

Power Management

junn-hope, 2022-02-10:
Research and design means of distributing and managing power to the 3 boards- avionics, telemetry & flight control- and the camera

Closed 2022-03-29.

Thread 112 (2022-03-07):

ground station and onboard antenna designs

ianmuchyri, 2022-03-07:
Designing of a ground station antenna preferably a Yagi Uda antenna operating at 2.4GHz. Design of suitable antenna to be fitted on rocket body.

ianmuchyri, 2022-03-15:
attached below is a design proposal and simulation results for a surface-mounted dipole antenna array for the onboard computer operating at 2.4GH
[onboard antenna array.pdf](https://github.com/nakujaproject/internship2022/files/8255750/onboard.antenna.array.pdf)
z

ianmuchyri, 2022-10-13:
We decided to purchase the antenna. the fabrication may be considered for future developments

Closed 2022-10-13.

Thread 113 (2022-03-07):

Integration of Redundant pressure and altitude sensors

Simbona, 2022-03-07:
Adding alternatives to the MPU 6500 and BMP 280 sensors on the flight control computer

0x6f736f646f, 2022-03-29:
Will not be implemented

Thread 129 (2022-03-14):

Review matching circuit

georgebangeboss, 2022-03-14:
Reference https://github.com/nakujaproject/N2-onboardTelemetryComputer/issues/5

0x6f736f646f, 2022-03-16:
@georgebangeboss is the matching circuit correct?

Closed 2022-03-16.

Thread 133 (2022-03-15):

Review voltage regulator circuit

Simbona, 2022-03-15:
>> Review the voltage regulator circuit if it works

>> A simulation on proteus or multisim will be great

What is the motivation/use case for changing the behaviour?
-- Reduce 5V to 3.3V

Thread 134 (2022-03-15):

Review I2C lines for Flight control and Avionics

Simbona, 2022-03-15:
>> Review the I2C lines if they are correctly placed

>> Do we need pull up or pull-down resistors?

What is the motivation/use case for changing the behaviour?

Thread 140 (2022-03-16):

Review Lora Module

georgebangeboss, 2022-03-16:
ref https://github.com/nakujaproject/N2-onboardTelemetryComputer/issues/10#issuecomment-1066454962

georgebangeboss, 2022-03-22:
matched the circuit

Closed 2022-03-22.

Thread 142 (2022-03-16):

Review reverse voltage protection circuit #8

cmucheru, 2022-03-16:
Reviewed the reverse protection circuit.

Closed 2022-03-29.

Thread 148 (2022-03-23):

Print yagi uda antenna

0x6f736f646f, 2022-03-23:

ianmuchyri, 2022-10-13:
No longer being considered as an option. We purchased an outdoor antenna for use

Closed 2022-10-13.

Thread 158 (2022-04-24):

Ground Station manual override parachute

georgebangeboss, 2022-04-24:
Issue copied at [here](https://github.com/nakujaproject/N2-flight-software/issues/20)

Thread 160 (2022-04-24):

Test GPS inside fibre glass body tube

georgebangeboss, 2022-04-24:
Copied at [here](https://github.com/nakujaproject/N2-flight-software/issues/23)

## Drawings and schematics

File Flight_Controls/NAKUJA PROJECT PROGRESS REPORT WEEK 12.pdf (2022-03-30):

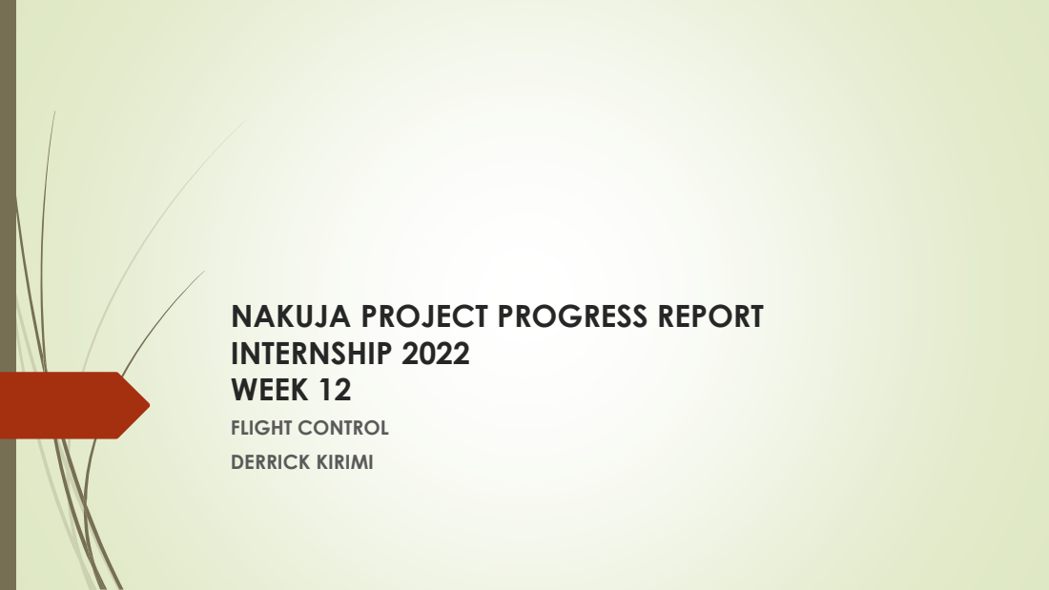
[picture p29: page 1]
FLIGHT CONTROL; DERRICK KIRIMI

NAKUJA PROJECT PROGRESS REPORT
INTERNSHIP 2022
WEEK 12

# TASKS LAST WEEK

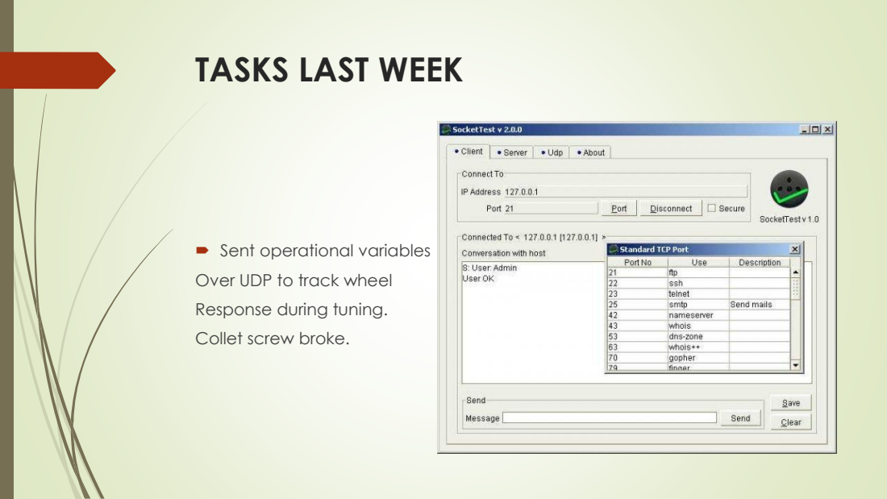
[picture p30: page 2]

Sent operational variables
Over UDP to track wheel
Response during tuning.
Collet screw broke.

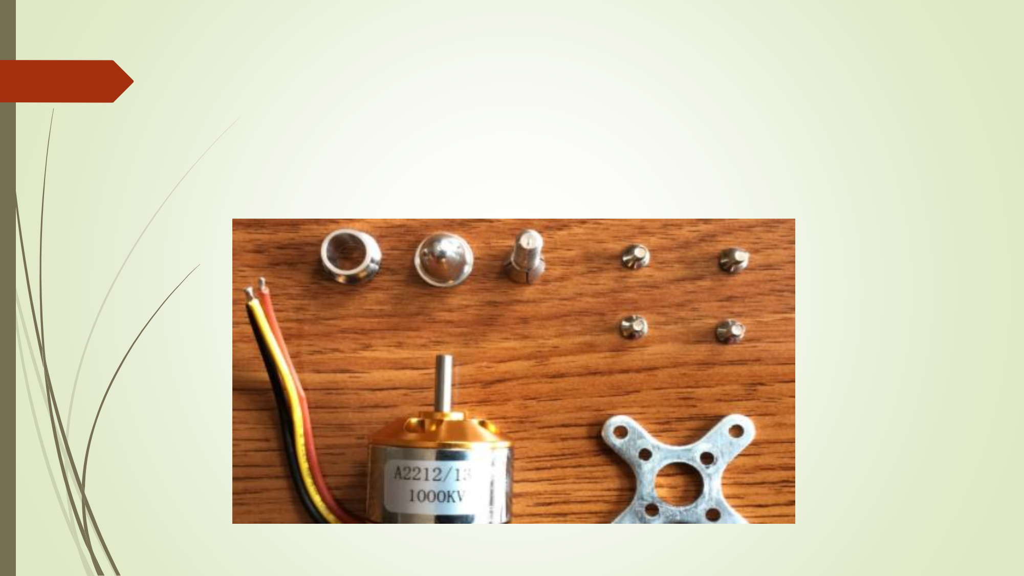
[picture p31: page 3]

# Brief mention of research topics

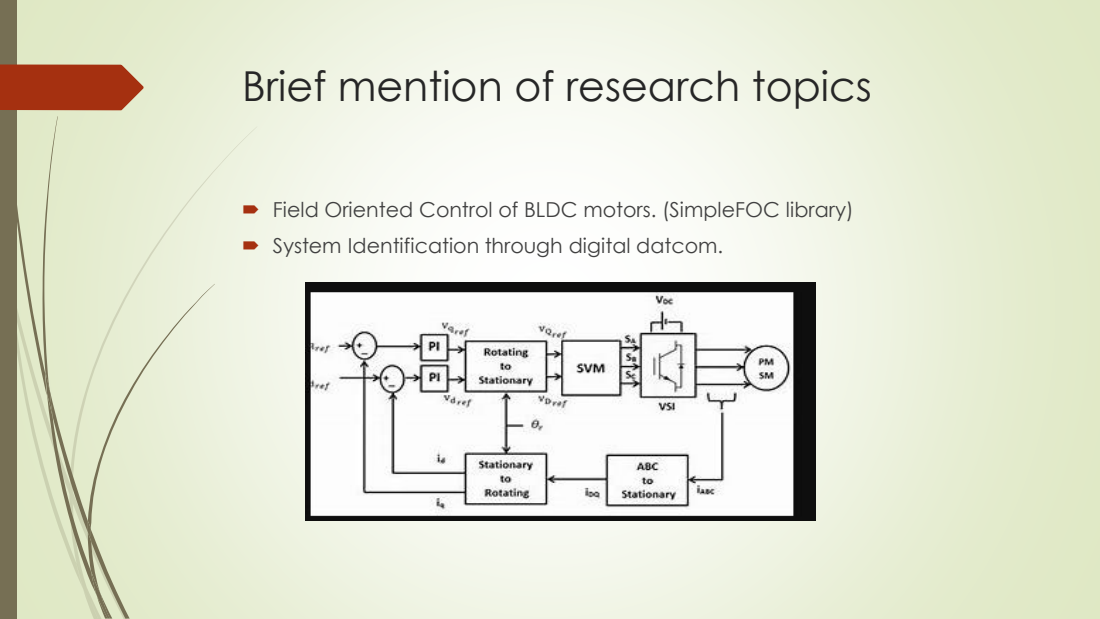
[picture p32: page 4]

Field Oriented Control of BLDC motors. (SimpleFOC library)
System Identification through digital datcom.

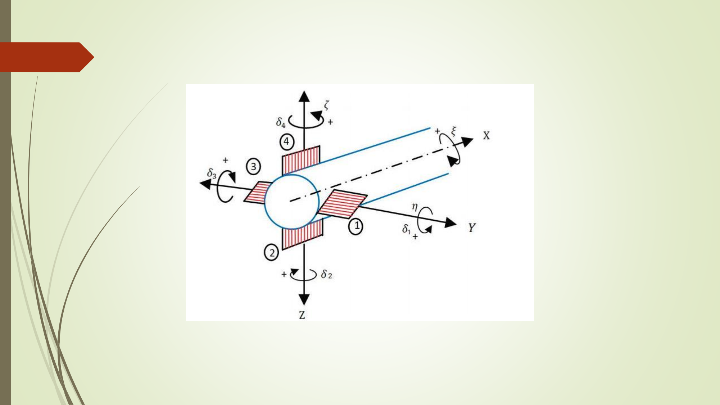
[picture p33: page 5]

# TASKS THIS WEEK

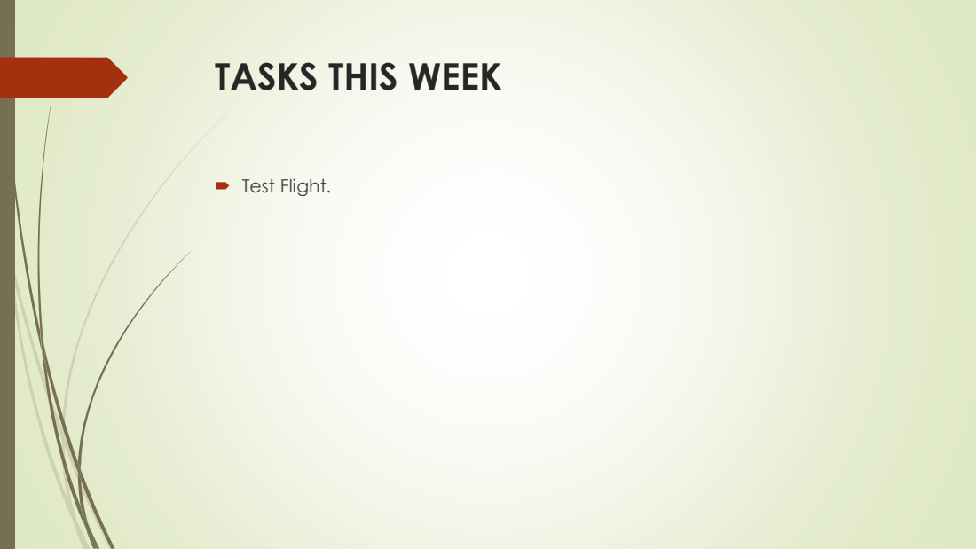
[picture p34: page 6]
Test Flight.

# TIMELINE Timeline

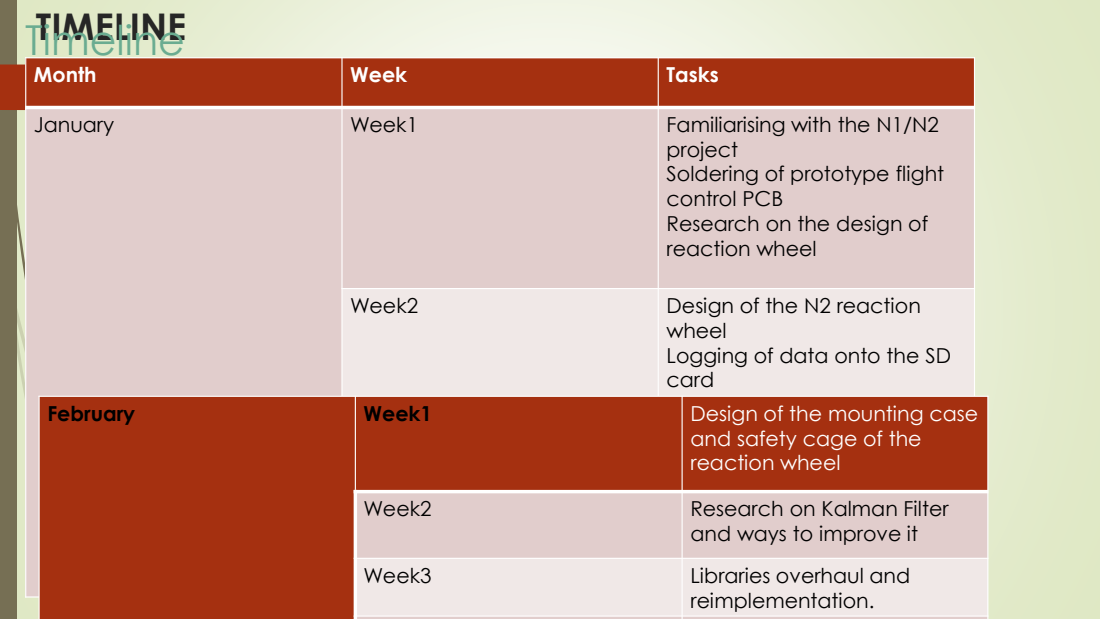
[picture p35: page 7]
January; Week1; Familiarising with the N1/N2; Week3; Week4; February; Design of the mounting case; Week2; Research on Kalman Filter; Libraries overhaul and; reimplementation.

Month | Week | Tasks

project Soldering of prototype flight control PCB Research on the design of reaction wheel

Week2 | Design of the N2 reaction wheel Logging of data onto the SD card

Research on the mounting case and safety cage of the reaction wheel | and safety cage of the reaction wheel

and ways to improve it

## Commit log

2022-01-26 updated the powerepoint slide
2022-02-22 Create CAD
    Here's a list of CAD drawing parts for the N-2 rocket
2022-02-22 Create Rocket Assembly
2022-02-22 Add files via upload
    This is the rocket assembly on Inventor
    [N-2 rocket assembly1.iam]
